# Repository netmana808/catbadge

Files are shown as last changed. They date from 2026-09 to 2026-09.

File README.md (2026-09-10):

# CatBadge case

A printable enclosure for the **large Retia CatBadge / ScriptKitty badge**, with screwless case catches, an independently removable battery cover, and six flanged buttons.

**Latest files: v8.7 case, v8.7a rear adhesion pads, and v8.7b taller buttons.** These are prototypes. Digital checks pass; printed fit, snap force, adhesion improvement and durability remain unverified.

**[Download the latest release](https://github.com/netmana808/catbadge/releases/tag/v8.7b)** · [Assembly guide](work/v8_7/README.md) · [Printing notes](PRINTING.md)

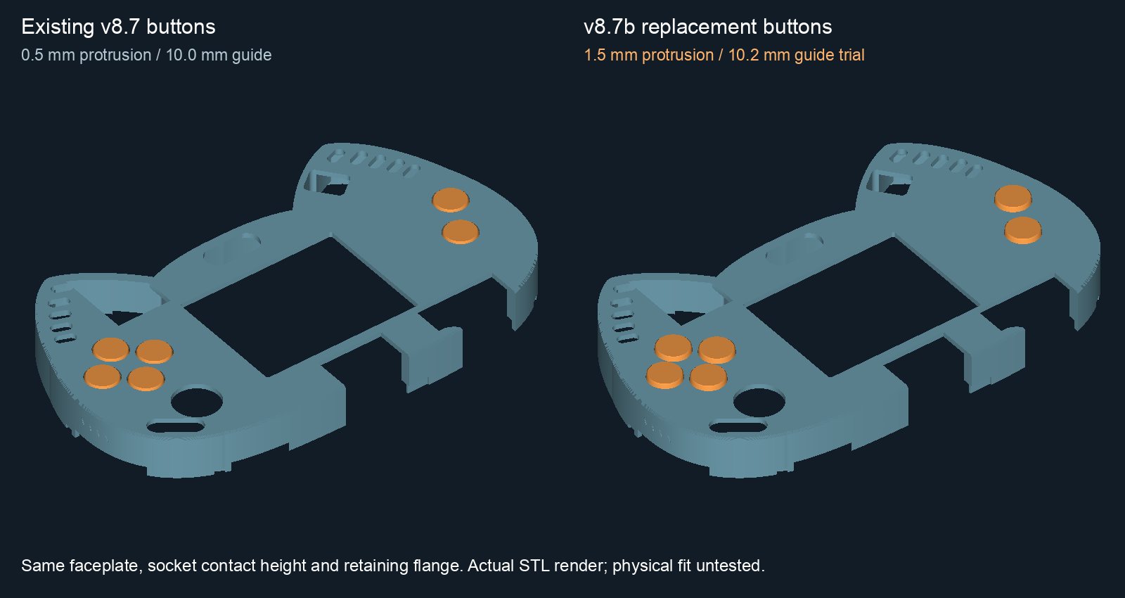
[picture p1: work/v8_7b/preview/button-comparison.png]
Original and taller buttons in the same faceplate, rendered from exported meshes


## Choose what to print

| What you need | Files | Notes |
| --- | --- | --- |
| Complete closed-back case | [v8.7 combined 3MF](work/v8_7/CatBadge-v8.7-COMBINED-CLOSED-BACK.3mf) | Front, rear, cover and original-height buttons; spring-antenna access retained. |
| Rear with extra bed attachment | [v8.7a rear-only 3MF](work/v8_7a/parts/CatBadge-v8.7a-Rear-Tray-Adhesion-Tabs.3mf) | Four removable pads; reuse the v8.7 front and cover. |
| Taller buttons for the same front | [v8.7b six-button set](work/v8_7b/CatBadge-v8.7b-SIX-cap_G10p2_S3p2_PLUS1mm.3mf) | Provisional 10.2 mm guide / 3.2 mm socket; test first. |
| Case snap test | [v8.7 snap coupons](work/v8_7/PRINT_FIRST_v8.7_Snap_Only.3mf) | Compare retention before printing a complete case. |
| Button fit comparison | [v8.7b six fit trials](work/v8_7b/PRINT_FIRST_v8.7b_Button_Fit_Trials.3mf) | Guide and socket sizes are separate choices. [Identification map](work/v8_7b/preview/fit-trial-layout.png). |
| Pad-removal test | [v8.7a ear-tip coupon](work/v8_7a/tests/PRINT_FIRST_v8.7a_Ear_Pad_Removal.3mf) | Tests contact and trimming, not full-case warping. |

**For the newest combination**, use a [v8.7 front](work/v8_7/parts/faceplate.3mf), [v8.7 battery cover](work/v8_7/parts/battery_cover.3mf), v8.7a rear and your selected v8.7b buttons. The v8.7 combined file retains its original rear and buttons; it does not automatically include the later replacements.

The [NO-SPRING-ONLY front](work/v8_7/parts/faceplate_NO_SPRING_ONLY.3mf) and [matching combined kit](work/v8_7/CatBadge-v8.7-COMBINED-CLOSED-BACK-NO-SPRING-ONLY.3mf) require the original spring antenna to be absent. Both front variants retain SAO access.

All STL/3MF dimensions are millimeters. The 3MFs contain geometry only, without a printer profile or G-code. Use release assets for direct downloads, or GitHub's raw/download button for individual files.

## What's new

### v8.7 — closed rear and reinforced joint

- Closes the rear vents and large rear-ear windows while retaining battery and service access.
- Increases the rear floor from 1.6 to 2.4 mm, outward from the board.
- Widens four catches to 8 mm and thickens the mating tongue to 1.4 mm.
- Uses 0.35 mm nominal engagement, with 0.25 / 0.35 / 0.45 mm coupons.
- Moves the battery-cover interface outward 0.8 mm to match the thicker rear.

The screen opening remains **52.5 × 40 mm**, with LED slots, open SAO access, and the antenna connector in the rear tray's outer ear slope. Main shell depth is approximately **23.2 mm**, or **31.5 mm over the battery cover**. Loaded-holder design envelope: **15.7 × 32.7 × 59.7 mm**. Actual adapter body, cable bends and complete electronics clearances need a fit check.

### v8.7a — removable rear adhesion pads

Two **24 mm diameter** ear-tip pads and two **20 mm** lower-corner pads increase first-layer contact. They are **0.4 mm thick** and should be trimmed flush after cooling. Print envelope: **154 × 112 mm** before a brim. The case interfaces match v8.7 within export precision.

This responds to a report of both rear ears lifting during a PETG print. The failed file and settings were not confirmed, so the pads are a trial rather than a proven cure. [Rear reprint guide](work/v8_7a/README.md).

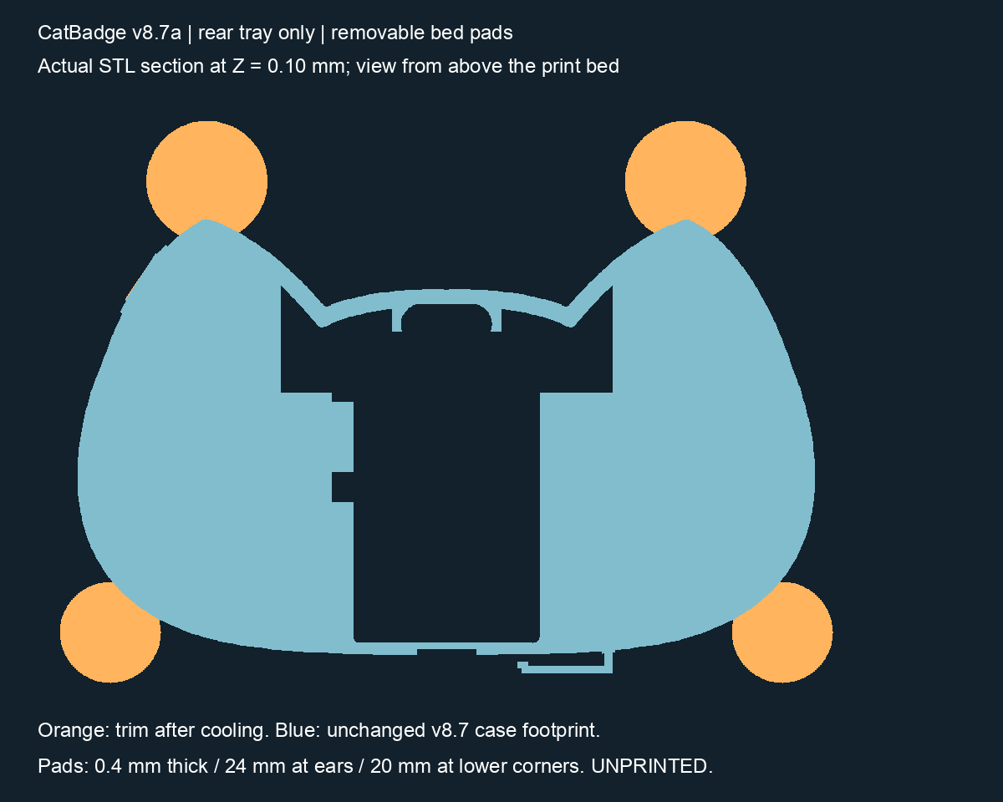
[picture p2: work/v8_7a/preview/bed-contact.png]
Actual rear STL bed-contact section; orange areas are removable pads


### v8.7b — taller button fit trials

- Adds **1 mm** to the exposed end: nominal protrusion increases from **0.5 to 1.5 mm**.
- Offers **10.0 / 10.2 / 10.3 mm** guides in the existing 10.6 mm opening.
- Retains socket contact height, 1.5 mm socket depth, 4.8 mm boss and 11.4 mm retaining flange.
- Includes **3.0 / 3.1 / 3.2 / 3.3 mm** socket trials and six-button sets for the provided combinations.

A closer guide is intended to reduce side play but must still move freely. Flanges stop outward escape; buttons can still fall out through the rear of a removed front. [Button selection guide](work/v8_7b/README.md).

## Printing and assembly

1. Start with the relevant fit coupons and inspect the sliced paths.
2. Keep the supplied orientations: **front and buttons face down; rear and cover exterior down**. Button sockets face up. The parts are designed for printing without supports at 0.20 mm layers; check your slicing result.
3. Print the padded rear separately, centered on the bed, with a connected brim. Let it cool before trimming while supporting the ears.
4. Check the empty case before installing electronics. With power removed, test free button sliding and gentle socket fit. Every button must release; no switch should be held down at rest.
5. Keep the matched v8.7 interfaces. V8.7a and v8.7b replace only their named parts; compatibility with older complete cases is not established.

See [PRINTING.md](PRINTING.md) for the proposed PETG starting trial. No script starts a printer job.

## Source and rebuild

Source is Python geometry code using NumPy, Shapely and Trimesh/Manifold. The full-case pipeline also uses OpenSCAD; VTK/Pillow render previews. This is not a native STEP model.

Use Python 3.12 and install OpenSCAD separately for full-case builds:

```sh
python3.12 -m venv .venv
.venv/bin/python -m pip install -r work/v8_7/requirements-resolved.txt
bash rebuild.sh v8.7b   # Buttons, checks and preview
bash rebuild.sh v8.7a   # Padded rear, coupon and checks
bash rebuild.sh v8.7    # Full case, coupons, checks and previews
```

`bash rebuild.sh all` runs all three. `v8.4` remains available for the original public release. The root script detects OpenSCAD on PATH or in `/Applications/OpenSCAD.app`; use `OPENSCAD_BIN=/path/to/OpenSCAD` for a custom executable and `CATBADGE_PYTHON` for an existing Python environment.

To check supplied case files without regenerating them:

```sh
.venv/bin/python work/v8_7/source/validate_v87.py --standalone
.venv/bin/python work/v8_7/source/check_overhangs.py
```

The root `rebuild.sh` is the public entry point. Historical local-workspace scripts are retained as provenance; some require unpublished baseline inputs. Standalone validation skips only unavailable historical-input checks and still checks supplied meshes and mechanical interfaces. The v8.7a/v8.7b builders include their reference meshes and validation.

## Validation and history

| Version | Digital checks | Physical status |
| --- | --- | --- |
| [v8.7](work/v8_7/validation.json) | 20 printable solids; formats, layout, snap/cover/button clearances; [layer support checks](work/v8_7/overhangs.json) | Complete fit, strength and snap feel unverified |
| [v8.7a](work/v8_7a/validation.json) | Single-solid rear/coupon; preserved case interfaces; additions confined to bed pads within export tolerance | Adhesion improvement and removal untested |
| [v8.7b](work/v8_7b/validation.json) | Six variants; 648 free-motion and 72 flange-stop checks; retained socket interfaces | Sliding fit, socket grip and switch return untested |

These checks do not establish manufacturing tolerances or allowable switch stroke. Only the original v0.1 tray/open frame has explicit user-confirmed fit. Release assets include source, validation, previews and SHA-256 checksums. The [v8.4 release](https://github.com/netmana808/catbadge/releases/tag/v8.4) remains available.

## Attribution

Independent enclosure for [RetiaLLC/DefconBadge2026](https://github.com/RetiaLLC/DefconBadge2026), not an official Retia product. PCB geometry and component-source credit belong to the badge designers. See [ATTRIBUTION.md](ATTRIBUTION.md).

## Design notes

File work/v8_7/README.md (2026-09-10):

# CatBadge v8.7 — closed back and reinforced snap rim

V8.7 responds to a physical print reported as flimsy and difficult to snap together satisfactorily. The printed version and slicer settings have not been confirmed, so this is a geometry revision with fit trials, not a diagnosis of the printer.

## Changes

- Close the six rear vent slots and the large rear ear windows. Battery access, UART, QWIIC, lanyard and the existing side service openings remain available. A continuous rear border ties the center section to the ears beneath the side-access header cutouts.
- Increase the main rear panel from **1.6 to 2.4 mm**, outward from the board. Its inner face remains at Z=-8 mm, preserving the existing rear component clearance.
- Increase the overlapping faceplate tongue from **1.15 to 1.4 mm nominal thickness** and widen all four catches from **5 to 8 mm**.
- Select **0.35 mm engagement**, with 0.25, 0.35 and 0.45 mm print-first trials. Preserve the 0.30 mm nominal mating gap. Widen the matching tray pockets and move the release notches clear of the wider catches.
- Move the battery cover and its mating tabs/slots/latch interface outward **0.8 mm** for the thicker rear panel. Cover shape, independent sliding access and the loaded-holder envelope are retained.
- Retain the v8.4 exterior finishing, beveled caps, 52.5 x 40 mm screen opening, LED slots, open SAO and rear outer-ear antenna port.

The catches remain opposed ramped detents, designed to release through outward rim flex. A more substantial rim, wider engagement and a closed rear panel are intended to improve feel; no physical retention force, stiffness or cycle-life claim follows from the CAD checks. These are not square permanent locking hooks.

**Print the v8.7 faceplate, rear tray and battery cover as a matched set.** Earlier shells are not the fit target. V8.4 button caps retain their geometry and may be reused if their sockets already fit gently.

## Downloads and orientation

- `CatBadge-v8.7-COMBINED-CLOSED-BACK.3mf`: default faceplate with original spring-antenna access, rear tray, battery cover and six 3.2 mm TRIAL socket caps.
- `CatBadge-v8.7-COMBINED-CLOSED-BACK-NO-SPRING-ONLY.3mf`: alternative faceplate; use only if the original spring antenna is absent. SAO remains open.
- **`PRINT_FIRST_v8.7_Snap_Only.3mf`**: three engagement trial lids and their shared tray coupon; start here.
- `PRINT_FIRST_v8.7_Fit_and_Comfort.3mf`: 16 objects, including three rim-fit trials, shared tray coupon, battery latch pair, four socket trials, front-button coupon, LED/SAO and screen checks, finishing samples and a closed rear-ear sample.
- `PRINT_FIRST_v8.7_Comfort_Only.3mf`: the three finishing samples.

Individual STL and 3MF files are in `parts/` and `tests/`. Each complete kit has nine named objects in a nominal 220 x 220 mm layout before brims. All units are millimeters. These are geometry-only 3MFs, without a printer profile or G-code.

Keep the exported orientations: faceplate and caps face down; rear tray and cover exterior down. The exported geometry is checked with a 0.2 mm layer / 45-degree support envelope. Inspect the actual sliced paths and any local bridges before printing.

## PLA+ print and fit trial

With a **0.4 mm nozzle**, a starting trial is **0.20 mm layers, four walls/perimeters, and six top/bottom layers**, using the filament maker's temperature range. This is a suggested trial, not a verified Anker/eufy profile. The 1.4 mm tongue may resolve into fewer than four extrusion lines; inspect the preview for filled, continuous material rather than relying on the wall-count setting alone. Shell walls matter more than simply increasing infill.

1. Print the shared rim tray and 0.25 mm engagement lid first. Compare the 0.35 mm trial if the first is loose. Use 0.45 mm only as a comparison after the gentler trials; do not force a tight joint.
2. Confirm that the coupon seats fully, has useful retention and releases through the notch. Gaps between extrusion lines, split layers, whitening or cracks are failed results.
3. Check repeated gentle opening/closing; twenty cycles can be an initial screening test, not lifetime qualification. The cropped coupon has different stiffness from the complete perimeter.
4. Check both empty v8.7 shell halves before fitting electronics. The combined file uses the middle 0.35 mm trial. Test the shifted battery cover and latch separately.
5. For untested cap sockets, start at 3.3 mm and work downward to a gentle fit. The combined kit's 3.2 mm socket remains provisional.

If the halves cannot seat, check for first-layer spread, an unseated PCB/cap, misplaced antenna cable or tight engagement. If a fully seated seam barely retains, compare the next engagement coupon. If the printed rim itself separates along layers or shows gaps, check extrusion and layer bonding before increasing engagement. Do not use screws, glue or force to overcome a mismatch.

## Assembly and reopening

Remove power. Fit the antenna adapter with its real metal nut and route its cable clear of the board seat, rim and battery-cover path. Check the newly enclosed rear-ear area: it retains 8 mm nominal rear clearance, but the actual adapter body, U.FL lead bend and other components are not fully modeled. Keep the existing side connector and top UART/QWIIC paths clear.

Seat the PCB and gently fitted caps, align the faceplate, then seat the perimeter next to the catches. Do not press on the screen or switches. Use a thin plastic pick in the exterior notches to ease the outer faceplate rim outward and lift it away, releasing catches progressively. Stop if the rim needs force or shows stress damage.

The digital release path prescribes up to 0.55 mm local outward displacement for the selected 0.35 mm engagement, then checks separation. This is a collision model, not a measured deflection limit or force recommendation.

To open the battery cover, press its bottom-edge latch toward the badge center, slide 3.2 mm toward assembly +X (right viewed from the front), and lift away from the rear. Install in reverse. The main case can stay closed.

Button flanges prevent outward escape while assembled; caps can still exit the rear of a removed faceplate. No extra keeper plate or case screws are required.

## Dimensions and validation limits

- Width: approximately **147.96 mm**, unchanged.
- Main shell depth: **23.2 mm**; over the battery cover: **31.5 mm**; including button faces: **32.0 mm**. The 0.8 mm increase buys rear-panel thickness while preserving electronics clearance.
- Faceplate skin remains 1.6 mm. Screen opening remains **52.5 x 40 mm**, with right edge X=26.46 and left edge X=-26.04.
- Measured loaded holder: **15.7 high x 32.7 wide x 59.7 long mm**. Its assumed top remains at the PCB underside; leads and mounting offsets require a real fit check.
- The antenna bore remains a **6.5 mm trial** with a 2.4 mm clamping land; exact adapter fit is unverified.

`validation.json` reloads 20 unique printable solids, verifies STL/3MF surfaces and kits, and checks assembly, PCB seat, service access, button motion, rim engagement/release and battery-cover travel. Revision checks prove former vent/ear closure, increased engagement geometry, the cover translation and retained button geometry. They do not measure snap force or structural stiffness. `overhangs.json` checks 0.2 mm layers with 0.205 mm lateral growth and at most 0.025 mm² residual per layer.

The user has reported poor fit/feel on an earlier print; its exact version and settings are not yet confirmed. **V8.7 is unprinted and physically unverified.** Mesh/render checks do not establish thermal, drop, fatigue, connector or full electronic-assembly performance.

## Rebuild

From the local design repository, with its Python environment and OpenSCAD installed:

```sh
bash rebuild.sh v8.7
```

From the extracted ZIP, use Python 3.12, the dependencies in `requirements-resolved.txt`, and OpenSCAD on PATH:

```sh
python source/generate_v87.py --coupons
python source/validate_snaps.py
python source/check_overhangs.py --coupons
python source/generate_v87.py
python source/validate_v87.py --standalone
python source/check_overhangs.py
python source/render_v87.py
```

`generate_v87.py` is the entry point; earlier generators are geometry helpers. All previews are generated from exported meshes; PCB display geometry is only a simplified reference. The package contains source, parameters, parts, coupons, previews and reports. CRC and per-file SHA-256 checks verify the ZIP; download checksums are in `SHA256SUMS`.

## References and credit

- [RetiaLLC/DefconBadge2026](https://github.com/RetiaLLC/DefconBadge2026): original hardware and PCB outline. Independent enclosure; upstream design credit remains with its designers.
- [Protolabs snap-fit guidance](https://www.hubs.com/knowledge-base/how-design-snap-fit-joints-3d-printing/): local flexibility, width, strain, build orientation and fit iteration; printed tolerances are not universal.
- [Prusa layers and perimeters](https://help.prusa3d.com/article/layers-and-perimeters_1748): shell thickness and perimeter settings affect strength. The suggested PLA+ profile above still needs a coupon test.
- [Prusa modeling guidance](https://help.prusa3d.com/article/modeling-with-3d-printing-in-mind_164135): orientation, chamfers and tolerances.
- Supplied Cynthion case: earlier rim/catch reference only; original meshes are not redistributed.

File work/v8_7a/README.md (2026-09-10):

# CatBadge v8.7a — rear tray with removable adhesion pads

Back-only reprint trial for the report that both rear ears lifted off the bed. This is the v8.7 rear tray with four sacrificial bed pads; the original case geometry is preserved within export precision. Use with the existing **v8.7** front and battery cover. Compatibility with other versions is not established, and the reported failed print file is not confirmed.

- [Rear tray 3MF](parts/CatBadge-v8.7a-Rear-Tray-Adhesion-Tabs.3mf)
- [Rear tray STL](parts/CatBadge-v8.7a-Rear-Tray-Adhesion-Tabs.stl)
- [Print-first ear/pad removal coupon](tests/PRINT_FIRST_v8.7a_Ear_Pad_Removal.3mf)
- [Bed-contact preview](preview/bed-contact.png)
- [Digital validation](validation.json)

## What changed

Two 24 mm diameter pads overlap the ear tips; two 20 mm pads overlap the lower outside corners. All are 0.40 mm tall and join the case directly at bed level. They add approximately 1,434 mm² of first-layer contact and 572 mm³ of material. The complete print envelope is 154 × 112 × 12.2 mm, or at most 170 × 128 mm including an 8 mm brim.

These are removable adhesion aids, not permanent case extensions or overhang supports. The 2.4 mm rear floor, snap rim, PCB seat, antenna port, battery opening and cover interfaces retain the v8.7 geometry. Do not thicken the floor or add internal ribs for this trial: those require electronics-clearance review and would not directly anchor the ear tips.

The pads target corner lifting but do not guarantee a warp-free print. The cause of this print's lifting remains unconfirmed. [Prusa's warping guidance](https://help.prusa3d.com/article/warping_2011) recommends a brim and, for persistent local lifting, small removable cylinders a few layers tall. The particular dimensions here are a design trial, not a manufacturer-validated M5C recipe.

## Reprint

1. Print the small coupon first to check first-layer contact and pad trimming. It is a cropped real ear tip with its pad and 2.4 mm floor. It does not predict full-case thermal warping or test the snaps.
2. Import the rear **by itself**, at 100% scale. Keep its exterior flat face and all four pads on the bed, open interior facing up. Center it on the plate.
3. For an M5C with compatible PETG, the proposed adhesion trial is 0.20 mm first/subsequent layers, four walls, 20 mm/s first layer, 240°C nozzle / 80°C bed, 8 mm outer brim with zero gap. Supports stay off. The 3MF contains geometry only; enter settings in your slicer. See the public repository PRINTING.md for context.
4. In the sliced preview, check that each pad touches the case and prints for two layers, and that the brim joins the exterior/pads. No slicing or printer job was performed during this CAD change. Keep direct AC/fan drafts away and prepare the actual plate surface appropriately; its coating remains unconfirmed.
5. Let the print and plate cool. Support each ear while carefully trimming the thin pads flush to the original case outline. Avoid twisting an ear to snap off a pad. Clear brim/pad remnants before trying the front and battery cover.

Reuse your front and cover if they are v8.7 and usable. No new screws or permanent support plate are required. Record the exact source file, selected profiles, whether corners stay down, pad-removal behavior and fit. Physical print results are pending.

## Source and verification

From the public checkout run `bash rebuild.sh v8.7a`. This rebuilds only v8.7a. The included `reference/rear_tray_v87.stl` is the untouched v8.7 geometry input; the original version's parametric sources remain in `work/v8_7/source/`. The input hash is recorded in `validation.json`.

The standalone `source/build.py` also runs from an extracted package using a Python environment with `source/requirements.txt`. It creates the coupon first, exports and reloads both STL/3MF pairs, verifies millimeter units and named single-solid objects, compares the rear against the reference, checks holes remain open, and checks the 0.20 mm layer support envelope. Numerical acceptance is 0.003 mm³ for export residual volumes and 0.025 mm² for section differences, not a physical fit allowance. The actual maximum section difference above the pads is approximately 0.00023 mm².

The PCB source is RetiaLLC/DefconBadge2026; this is an independent enclosure prototype. Existing v8.7 physical fit uncertainties remain. Physical validation is pending.

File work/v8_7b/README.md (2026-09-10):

# CatBadge v8.7b — taller replacement buttons

Replacement buttons for the **existing v8.7 faceplate**, including its NO-SPRING-ONLY variant. No front, back, cover or keeper plate needs to be printed. Compatible by geometry with the v8.7a rear derivative. The printed front's exact version and button fit symptoms remain unconfirmed; these are physical fit trials.

- **[Print-first six-button fit comparison](PRINT_FIRST_v8.7b_Button_Fit_Trials.3mf)**
- **[Six matching buttons: 10.2 mm guide / 3.2 mm socket](CatBadge-v8.7b-SIX-cap_G10p2_S3p2_PLUS1mm.3mf)** — provisional default; choose after testing
- [Actual mesh comparison](preview/button-comparison.png)
- [Trial-plate identification map](preview/fit-trial-layout.png)
- [Validation report](validation.json)

## Changes and retained interfaces

The face extends **1.0 mm farther outward**, increasing nominal protrusion from **0.5 to 1.5 mm** above the local faceplate. The old cap's actual assembly top is Z=13.3 mm and the new one is Z=14.3 mm; the faceplate is Z=12.8 mm. An earlier generator default of Z=13.7 was superseded by v8.1 and is not the v8.7 export height.

The main trial increases guide diameter from **10.0 to 10.2 mm** inside the unchanged 10.6 mm guide bore. Nominal radial clearance reduces from 0.30 to 0.20 mm, intended to reduce side play. A 10.3 mm comparison offers 0.15 mm radial clearance. Smaller clearance can bind on an imperfect print; use the trial that moves freely rather than selecting the largest by default.

The 0.3 mm top bevel is retained. The flange transition remains 45 degrees for face-down printing. Socket roof/contact height stays at Z=6.8 mm; socket depth remains 1.5 mm, boss diameter 4.8 mm, entry chamfer unchanged. The retaining flange remains 11.4 mm diameter at Z=9.8–10.8 mm. The taller exposed end does not extend the socket toward the board. Actual switch preload, permissible stroke, return and socket grip still require checking on the real badge.

The existing flange prevents outward escape; these buttons can still fall out through the rear of a removed faceplate. No new latch or interference-fit retention is claimed.

## Fit trial

The comparison plate contains six separate caps. G identifies the faceplate guide diameter; S identifies the socket bore diameter. Both are CAD dimensions in millimeters.

| Position in supplied plate, viewed from above | Guide | Socket | Purpose |
| --- | ---: | ---: | --- |
| Front/lower row, left | 10.0 | 3.2 | Original guide diameter with new height |
| Front/lower row, middle | 10.2 | 3.2 | Main reduced-play trial |
| Front/lower row, right | 10.3 | 3.2 | Closer guide trial |
| Back/upper row, left | 10.2 | 3.3 | Looser socket trial |
| Back/upper row, middle | 10.2 | 3.1 | Smaller socket trial |
| Back/upper row, right | 10.2 | 3.0 | Smallest socket trial |

The slicer object names retain these dimensions. Keep them in order after removal; no tiny embossed identifiers were added to the sliding or contact surfaces. Auto-arranging changes the map, so use object names if rearranged.

1. Print at 100% scale with the exported **button faces down / sockets up** orientation. Use 0.20 mm layers and a 0.4 mm nozzle, with supports off. Use settings suitable for your material; there is no material profile or G-code embedded in these geometry-only 3MFs. Inspect first-layer spread and socket paths in the slicer.
2. Allow cooling and remove brim remnants without rounding the guide or filling the socket. Test each guide in the removed faceplate before installing it on a board. It must move freely without scraping or sticking. Compare all six locations in the actual front.
3. With power removed, start socket testing at 3.3 mm if the existing size is unknown, then work downward only to a gentle fit. Do not force the cap onto a switch. These separate trials distinguish faceplate clearance from socket grip.
4. Once assembled, verify every button releases and the switches are not held down at rest. The numerical collision offsets in the report are not permission to depress the real switch by that amount. A cap that only works when forced, sanded heavily or pressed against a stressed switch is a failed fit.
5. Use the matching `CatBadge-v8.7b-SIX-...` file for the selected combination. Six-piece files exist for each of the six tested combinations. Individual STL/3MF pairs are in `parts/`. If the best guide and socket require an unprovided combination, generate that combination and rerun the checks before printing a set.

The existing v8.7 combined case kit still contains its original caps. These button-only files are a separate replacement, not an updated full-case kit. If the original guide already sticks, neither the 10.2 nor 10.3 trial is a corrective recommendation; provide that result before shrinking a new guide variant.

## Verification and rebuilding

The standalone source uses the existing NumPy/Trimesh/Shapely/Manifold pipeline. Included reference meshes are untouched v8.7 faceplate variants and socket-cap exports, with hashes recorded in `validation.json`. Their upstream case/PCB attribution remains RetiaLLC/DefconBadge2026; this is an independent enclosure prototype.

From the public checkout: `bash rebuild.sh v8.7b`. From an extracted package, install `source/requirements.txt` in a local virtual environment, then run `python source/build.py` and `python source/render.py`. These produce geometry and reports only.

Validation reloads six printable STL/3MF pairs, checks single watertight solids, positive volume, names, millimeter units and matching bounds/volume. It checks retained socket/flange sections against each original socket size, the 1 mm height change, support envelopes at 0.2 mm layers, adjacent-button clearance, **648 cap/faceplate motion cases** and **72 flange-stop cases**. The collision tests include both faceplate variants, all six positions and ±0.1 mm lateral offsets at rest. A nonintersecting CAD assembly does not establish low friction, low wobble, switch return or manufactured fit. No print or actual slicer toolpath validation has occurred.

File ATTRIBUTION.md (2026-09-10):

# Attribution and licensing notes

- **Badge hardware:** [RetiaLLC/DefconBadge2026](https://github.com/RetiaLLC/DefconBadge2026), specifically `hardware/kicad/2024_def_con_badge_v1.kicad_pcb`. The enclosure helpers transcribe the board outline and selected footprint locations; they do not contain a complete electronics assembly. Credit and ownership of the upstream hardware remain with its designers.
- **Enclosure:** independent CatBadge case development, published by `netmana808`. The versioned releases retain the local project's source, geometry, measured constraints and validation artifacts.
- **Snap-fit reference:** locally supplied Cynthion case meshes informed the overlapping rim and catch concept. Those Cynthion meshes are not redistributed. Inspection measurements and file hashes are recorded in `work/v8_4/reference/cynthion_joint_measurements.json`; their dimensions are not validated CatBadge tolerances.
- **Tools:** NumPy, Shapely, Trimesh, Manifold, OpenSCAD, VTK and Pillow retain their respective licenses. Their applications, source distributions and fonts are not bundled.

The upstream repository did not expose a top-level license file or a detected license through GitHub when checked for this publication on 2026-09-09. No blanket license is assigned here to upstream or third-party material. Public availability alone should not be treated as a separate license grant. This publication does not relicense the badge hardware.

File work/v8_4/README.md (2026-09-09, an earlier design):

# CatBadge v8.4 — compact handheld polish

V8.4 softens exposed edges and adds subtle cheek grips while retaining the v8.3 size, four integral rim catches and independent sliding battery cover. It uses the existing PLA+ workflow and requires no case screws or separate keeper plate.

The front and rear exterior perimeter edges and battery-cover exterior edge have nominal **0.6 mm, 45-degree bevels**. The antenna mounting land, battery latch beam/root/tooth, sliding tabs and mating surfaces are protected from these cuts. The latch guards receive smaller 0.25 mm edge bevels and 0.30 mm rounded vertical corners to keep their corners within the print envelope. Layered perimeter bevels use 0.05 mm CAD increments; the button bevel is a continuous revolved surface.

All six button faces retain their flat round tops and gain **0.3 mm edge bevels** (9.4 mm flat top, original 10 mm guide diameter below the bevel). Stems, sockets, captive flanges and projection are preserved. Each cheek has **four shallow, rounded grip lines**, nominally 2.4 mm long, 0.8 mm wide and 0.25 mm deep, angled 20 degrees in mirrored directions. They are recessed into the outer wall, clear of catches and ports. The exterior entrances to the four release notches gain a 0.25 mm bevel; their internal access and catches remain unchanged.

This is an **unprinted PLA+ prototype**. The supplied Cynthion case informed the overlapping rim and local catches; its dimensions were not copied as validated CatBadge tolerances. Digital clearance and mesh checks do not establish physical snap force or fatigue life. Only the original v0.1 case has user-confirmed physical fit.

## Print files

- **`CatBadge-v8.4-COMBINED-HANDHELD.3mf`** — default, with original spring-antenna access retained in the left ear.
- `CatBadge-v8.4-COMBINED-HANDHELD-NO-SPRING-ONLY.3mf` — alternate with both ear faces closed around the LED stripes; use only if the original spring antenna is absent. SAO stays open.
- **`PRINT_FIRST_v8.4_Comfort_Only.3mf`** — cheek-grip coupon, battery-cover edge coupon and one 3.2 mm socket button cap: a quick three-piece feel check.
- **`PRINT_FIRST_v8.4_Fit_and_Comfort.3mf`** — all 15 coupons/trials: the comfort samples, three rim-fit trials, shared tray, battery latch pair, front-button section, four cap socket sizes, LED/SAO section and screen ring.

Each combined file contains **9 named objects**: one faceplate, one rear tray, one battery cover and six button caps. Select one combined file; the two faceplates are alternatives. There are no separate case pins, screws or nuts. The antenna adapter still uses its own real metal retaining nut.

Individual STL and 3MF files are under `parts/` and `tests/`. All geometry uses millimeters. The combined layout fits within a nominal 220 x 220 mm area before brims; it contains no printer profile or G-code. Keep the supplied orientations: faceplate and caps face down, tray and battery cover exterior down. The exported ramps pass the project's 0.2 mm layer / 45-degree support-envelope check. Inspect the slicer's actual thin-wall and first-layer paths before printing.

**V8.4 retains the v8.3 mechanical interfaces.** Exported-mesh checks cover both directions of mixed v8.3/v8.4 faceplate/tray, battery-cover/tray and button/faceplate combinations. Physical interchangeability still needs a fit check. These case halves do not mate with the earlier v8/v8.1 pin-mounted halves.

## Rim and catches

The outer faceplate tongue overlaps the rear tray at the seam. The nominal side gap is 0.30 mm; the faceplate tongue is approximately 1.15 mm thick and extends 3.0 mm below the original internal mating plane. The PCB seat and upper restraint retain the original 0.2 mm nominal board float. The tongue stays outside the board-clearance envelope.

Four 5 mm wide catches sit on the two upper cheek walls and two lower cheek curves. The catches point inward into matching tray recesses; the faceplate rim flexes outward during engagement/release. Both catch flanks are shallow ramps. These are releasable detents, not square locking hooks. Small exterior notches beside the catches allow a thin plastic pick to reach the seam without entering the PCB space.

The full case selects **0.25 mm nominal engagement**. The three coupon faceplates use 0.15, 0.25 and 0.35 mm engagement and share the same mating tray. These numbers describe engagement, not tongue thickness or clearance. Their files are named `PRINT_FIRST_rim_lid_0p15`, `0p25`, `0p35`, and `PRINT_FIRST_rim_tray`.

The catch roots use the continuous curved rim rather than narrow upright hooks. Local fit still depends on the filament, layer adhesion and slicer paths. The cropped coupon has different overall stiffness from the full case, so passing it is followed by an empty-case fit check. The inherited source parameter `P['catch_overlap']` in `source/generate_v83.py` controls full-case engagement; changing it requires regeneration and validation of both kits and parts.

## Fit sequence

1. Print the three-piece comfort set to assess the bevels, grip texture and button feel. Then print the shared rim tray and the 0.15 mm coupon lid first. Progress to the 0.25 mm and 0.35 mm trials only to compare retention. Select a fit that seats and releases gently. Whitening, cracking or a seam requiring force is a failed fit.
2. Check repeated opening and closing on the coupon. Twenty cycles is a useful initial screening exercise, not a lifetime qualification.
3. Check the two empty v8.4 case halves together before installing electronics. Confirm that the four catches retain the seam and release through their notches. The default full case corresponds to the 0.25 mm coupon.
4. Test button sockets from the largest 3.3 mm trial downward to a gentle fit. The combined case uses 3.2 mm provisionally. Verify the screen fit ring, retained button motion and any untested port/ear clearances.

## Assembly and reopening

Remove power. Fit the antenna adapter with its actual retaining nut, and route its cable clear of the rim, PCB seat and cover. Seat the board, then fit the six caps gently. Lower the faceplate squarely while aligning the cap faces with their guide holes. Apply light pressure at the perimeter adjacent to the catches until the rim seats. Do not use the screen, buttons or connector as pressing points. A misaligned case must not be forced together.

To reopen, use the small notches beside the four catches to ease the **outer faceplate rim outward**, then lift it away from the tray. A thin plastic pick can hold an already released section clear while working around the seam. Keep the pick in the external notch. Do not insert it over the PCB or lever against the board. Stop if the rim needs force or shows stress damage.

The release calculation prescribes up to 0.45 mm outward rim movement for the selected 0.25 mm trial, then checks axial separation. It is a geometric model, not an instruction to measure or force that displacement, and not a prediction of hand force or sequential release behavior. Verify the actual opening procedure on the empty case.

Button flanges prevent outward escape while assembled. The caps can still leave through the rear of a removed faceplate. There are no keeper plates or extra screws.

## Battery access

The existing cover remains independent of the main-case catches. To remove it, press its bottom-edge thumb latch toward the badge center (assembly +Y), slide the cover 3.2 mm toward assembly +X (right when viewed from the front), then lift it away from the rear. Install in reverse, sliding toward -X until it clicks. The main case stays closed during this operation.

The loaded holder envelope remains **15.7 mm high x 32.7 mm wide x 59.7 mm long**, with 1 mm modeled height allowance. Its modeled top is at the PCB underside; actual mounting offsets, leads and connector clearance still need physical verification.

## Preserved dimensions and access

- Main shell depth: **22.4 mm**; over the battery cover: **30.7 mm**; including button faces: **31.2 mm**. The new joint fits within this existing depth.
- Faceplate skin: **1.6 mm**; inner surface stays at Z=11.2 mm above the PCB underside, retaining 0.7 mm nominal clearance above the measured 10.5 mm screen before board float and print tolerances.
- Screen aperture: **52.5 x 40 mm**. Left edge X=-26.04, right X=26.46; Y=-27.99 to 12.01. The v8.1 right-side correction remains.
- Rear electronics clearance stays 8 mm and the floor stays 1.6 mm. No component heights or cable envelopes were guessed to reduce them.
- Six captive button flanges, all ten LED slots, open rotated SAO connector access, speaker, lanyard and existing service access remain.
- The 6.5 mm trial antenna port stays in the rear tray's outer left-ear slope with a 2.4 mm clamping land. Exact adapter shank, nut/washer, usable thread and cable-bend fit remain unverified.
- The default retains the left-ear spring access because removal of the original spring is unconfirmed. This revision makes no electrical, RF or firmware change.

## Validation and rebuild

`validation.json` records 19 unique printable solids; STL/3MF surface equivalence; 9 objects per full kit, 15 per full coupon kit and 3 per comfort kit; no overlap in the print layout; assembled clearances; retention at all four catches; outward-flex/separation checks for both faceplates; four external release-notch probes; battery-cover motion; 120 button offsets checked against both lids; PCB seat, screen, LED, SAO and antenna checks; exterior material removal without added bulk; all eight grip recesses; button and case bevels; protected mechanical sections; mixed v8.3/v8.4 assembly and motion checks; and protected baseline hashes.

`overhangs.json` checks exported print orientations one layer at a time at 0.2 mm, allowing 0.205 mm lateral expansion and at most 0.025 mm² numerical residual per layer. All parts pass this geometric envelope. It is not a printer-specific slicing or physical print result.

Previews are generated from the exported meshes. The front and rear assembly views include only a simplified PCB reference; electronics and cables are not modeled. `preview/snap_detail.png` is an actual cross-section of the mating meshes.

From the original repository root:

```sh
bash work/v8_4/run.sh
```

From an extracted package, with Python 3.12, the listed dependencies and OpenSCAD on PATH:

```sh
python source/generate_v84.py --coupons
python source/validate_snaps.py
python source/generate_v84.py
python source/validate_v84.py --standalone
python source/check_overhangs.py
python source/render_v84.py
```

`generate_v83.py`, `generate_v81.py`, `generate_v75.py` and earlier source modules are internal geometry helpers; use `generate_v84.py` as the build entry point. Finishing parameters live in `source/finish_v84.py`. Existing local tools were sufficient; no new system tooling was installed. The package includes source, parameters, individual meshes, test coupons, previews and reports. Archive CRC and each packaged file's SHA-256 are checked; distribution checksums are in `SHA256SUMS`.

## References

- [Prusa modeling guidance](https://help.prusa3d.com/article/modeling-with-3d-printing-in-mind_164135): bed-facing chamfers, print orientation and tolerance iteration.

- Local `cynthion_box.stl` and `cynthion_lid.stl`: measured overlapping rim and four local ramped catches; inspection measurements/hashes are recorded in `reference/cynthion_joint_measurements.json`. Supplied Cynthion mesh files are not redistributed in this package.
- [Formlabs snap-fit guide](https://formlabs.com/global/blog/designing-3d-printed-snap-fit-enclosures/): fit, print orientation, joint types and iterative physical testing.
- [Protolabs snap-fit guidance](https://www.hubs.com/knowledge-base/how-design-snap-fit-joints-3d-printing/): root geometry, deflection and clearance considerations. General process advice is not a PLA+ material qualification.
- [RetiaLLC/DefconBadge2026](https://github.com/RetiaLLC/DefconBadge2026): original PCB/outline source. Independent enclosure prototype; upstream design credit remains with its designers.

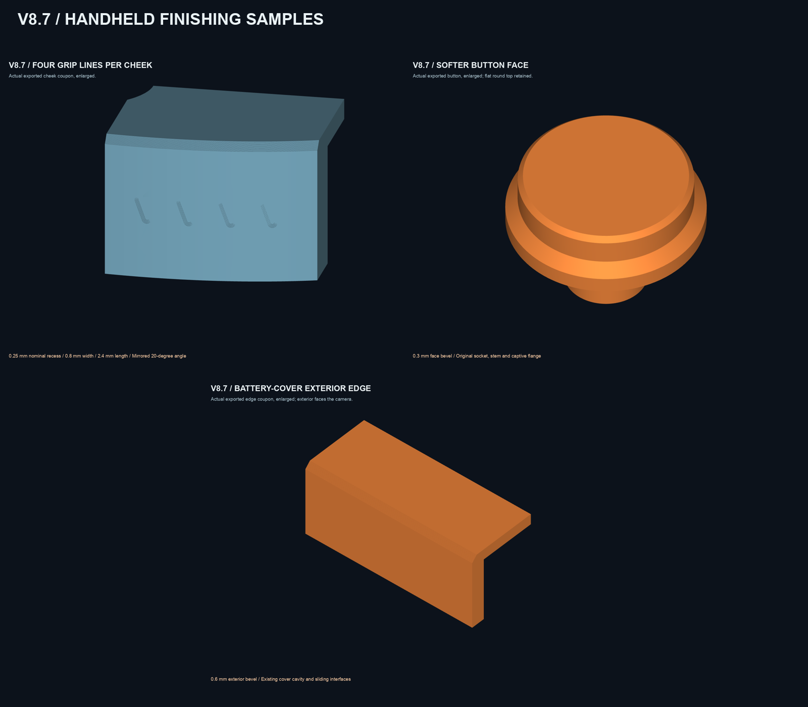
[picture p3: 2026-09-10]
work/v8_7/preview/comfort.png

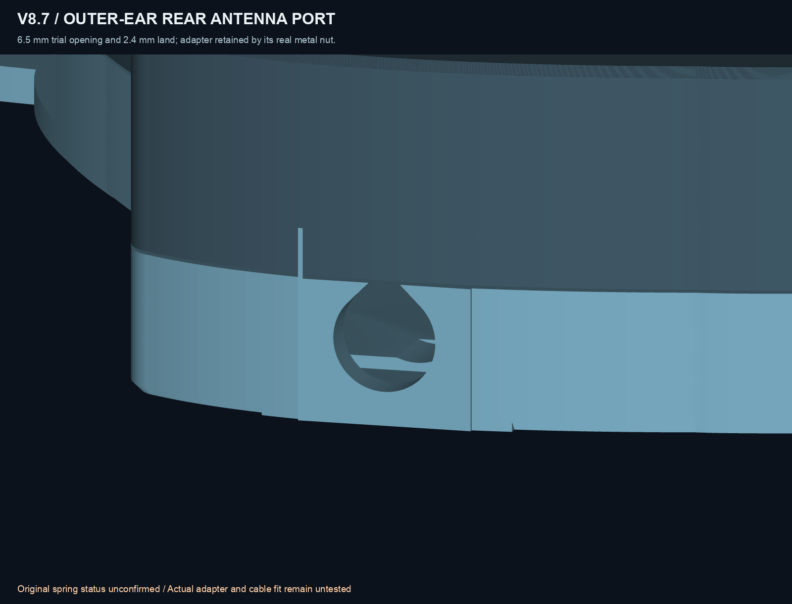
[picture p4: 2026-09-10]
work/v8_7/preview/antenna.png

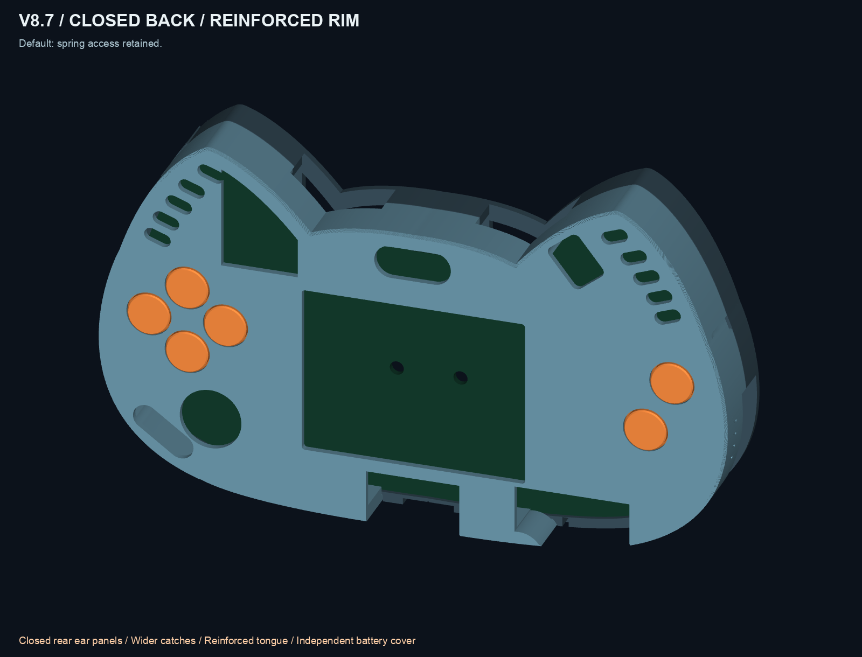
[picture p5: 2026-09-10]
work/v8_7/preview/front.png

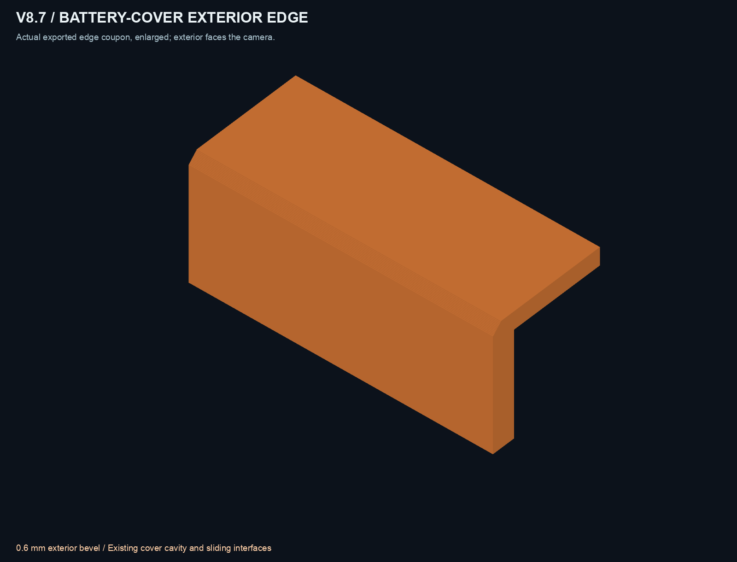
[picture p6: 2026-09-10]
work/v8_7/preview/cover_detail.png

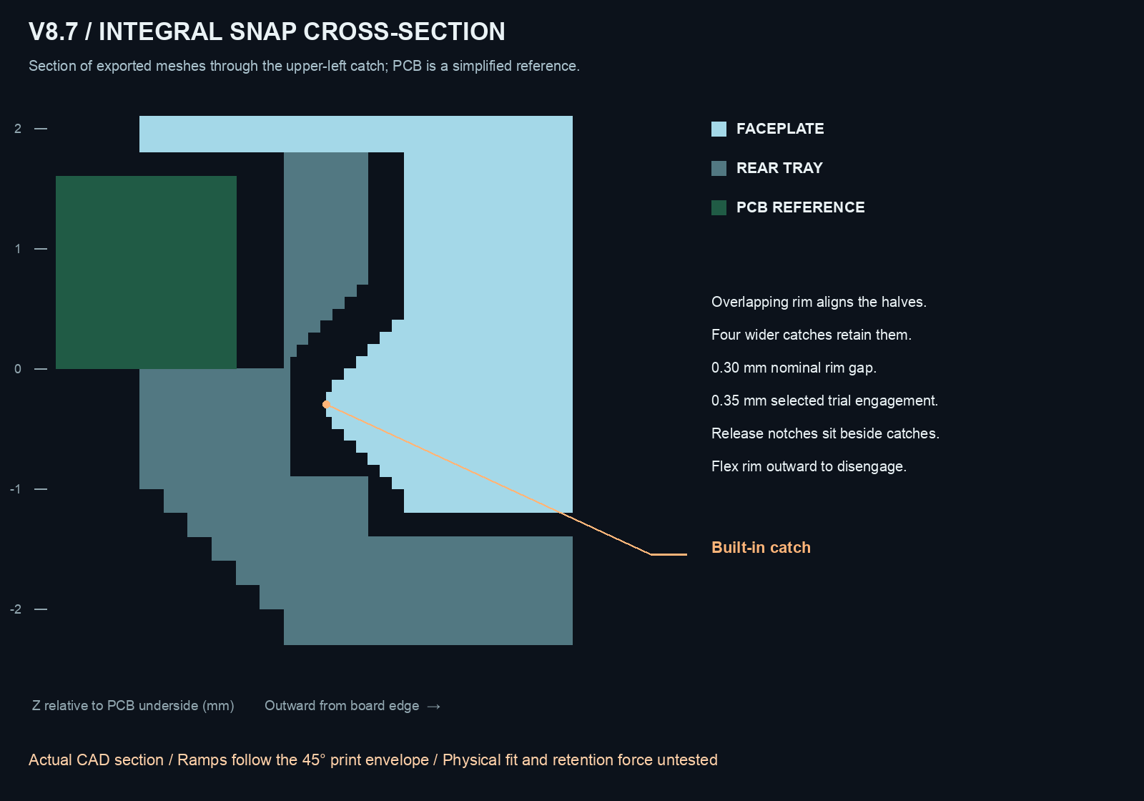
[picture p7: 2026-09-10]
work/v8_7/preview/snap_detail.png

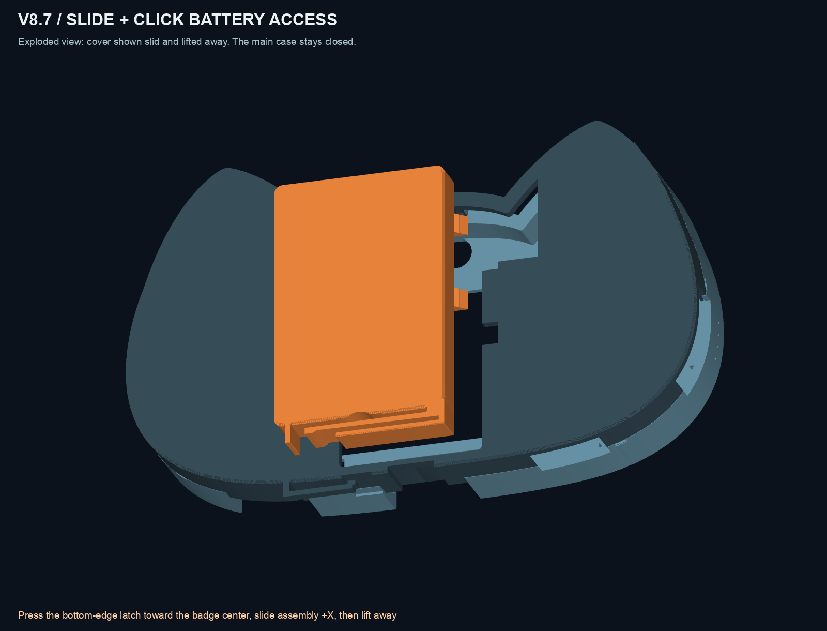
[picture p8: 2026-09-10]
work/v8_7/preview/rear.png

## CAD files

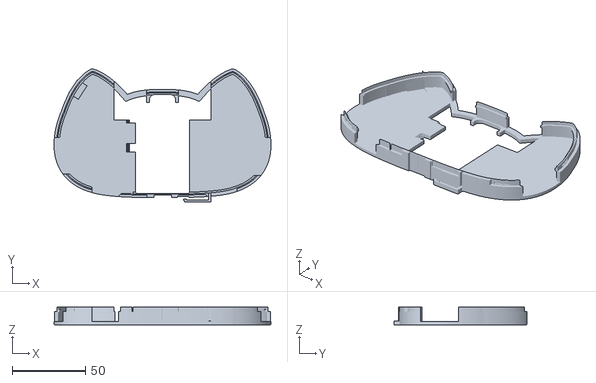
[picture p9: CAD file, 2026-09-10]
work/v8_7/preview/rear_tray_BLANK_ASSEMBLY.stl
148.0 x 90.8 x 12.2

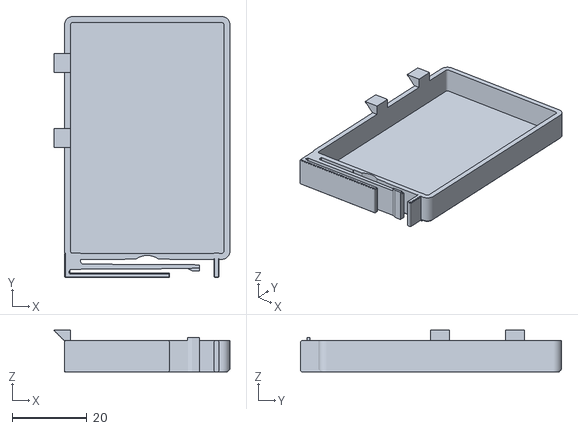
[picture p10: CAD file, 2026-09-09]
work/v8_7/reference/v84_battery_cover_ASSEMBLY.stl
47.0 x 69.8 x 11.1

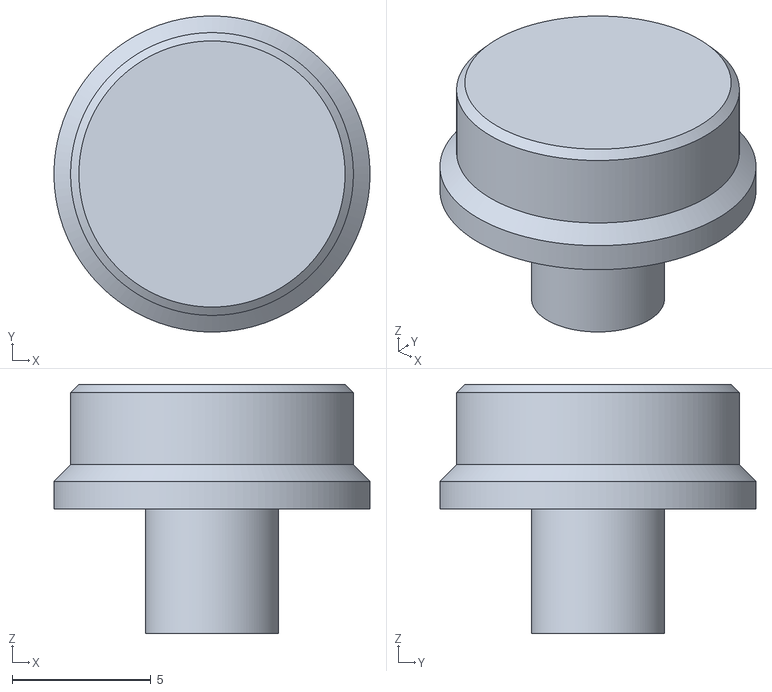
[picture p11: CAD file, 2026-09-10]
work/v8_7b/preview/cap_G10p2_S3p0_PLUS1mm_ASSEMBLY.stl
11.4 x 11.4 x 9.00

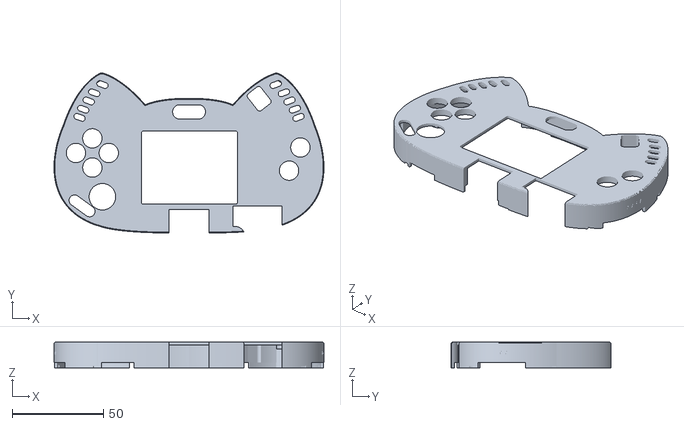
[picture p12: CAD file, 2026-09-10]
work/v8_7b/reference/faceplate_NO_SPRING_ONLY_ASSEMBLY.stl
148.0 x 87.7 x 14.0

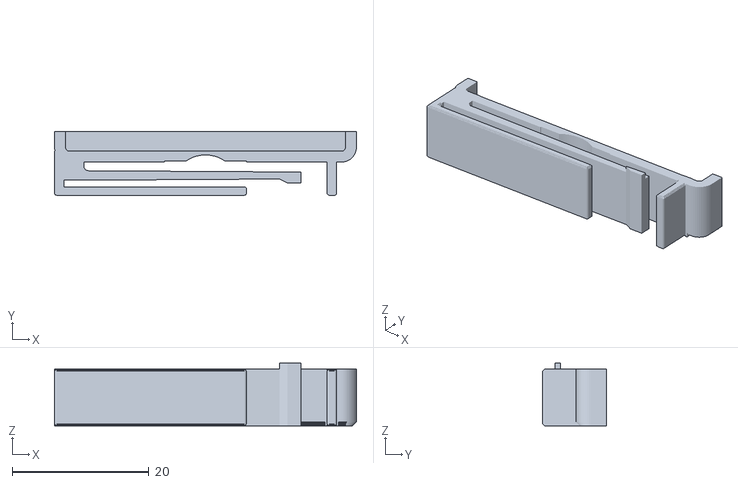
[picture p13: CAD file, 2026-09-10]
work/v8_7/preview/PRINT_FIRST_latch_cover_ASSEMBLY.stl
44.2 x 9.30 x 9.20

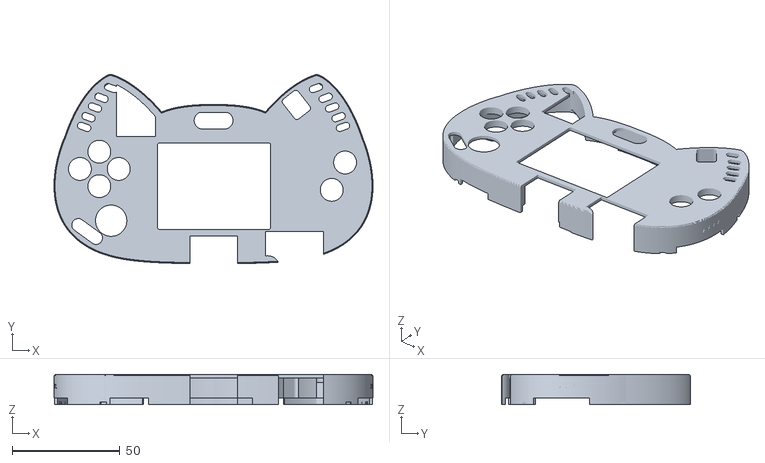
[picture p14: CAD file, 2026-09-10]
work/v8_7b/reference/faceplate_ASSEMBLY.stl
148.0 x 87.7 x 14.0

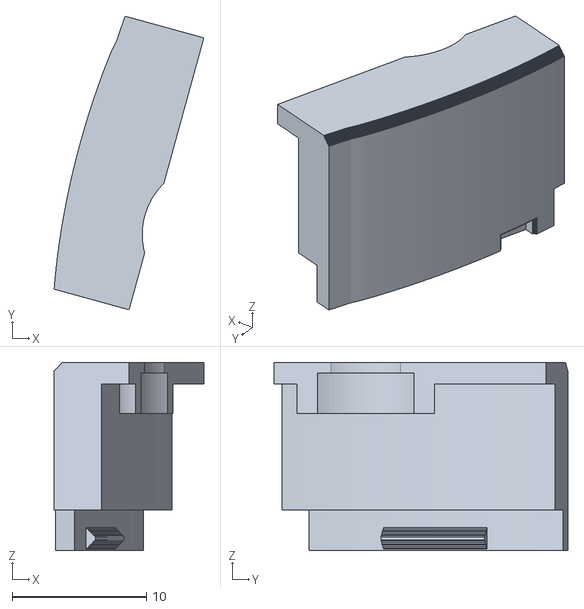
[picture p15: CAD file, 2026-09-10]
work/v8_7/preview/PRINT_FIRST_rim_lid_0p45_ASSEMBLY.stl
11.2 x 21.9 x 14.0

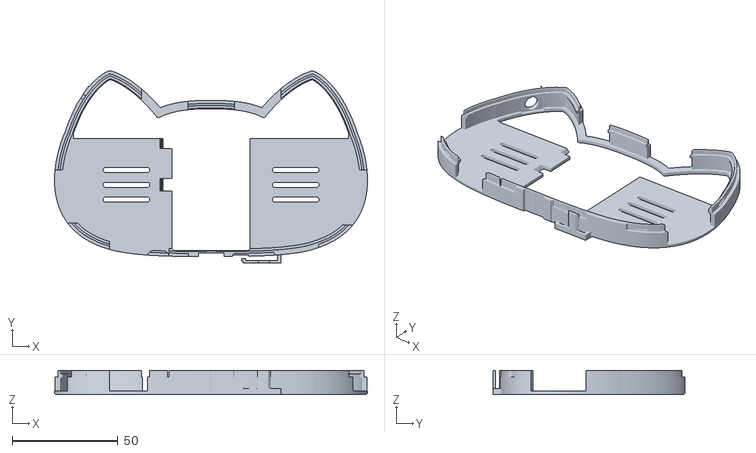
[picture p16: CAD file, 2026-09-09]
work/v8_7/reference/v84_rear_tray_ASSEMBLY.stl
148.0 x 90.8 x 11.4

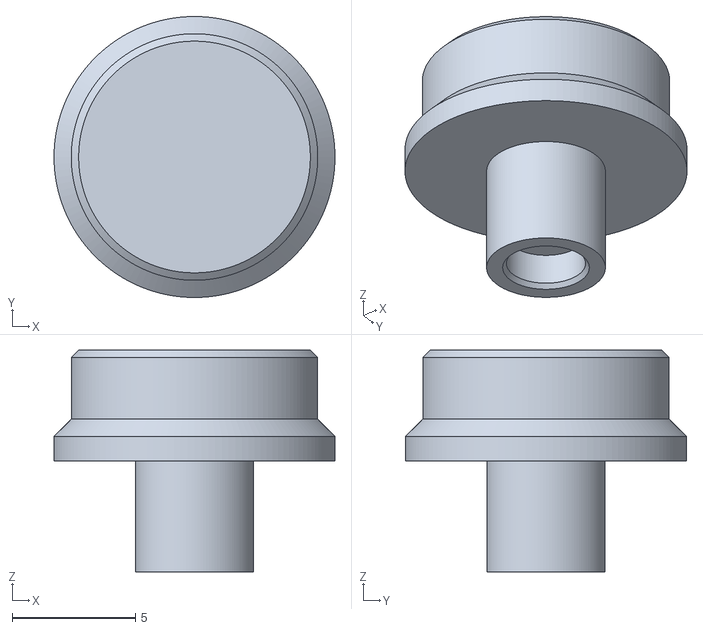
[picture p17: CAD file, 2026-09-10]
work/v8_7b/preview/cap_G10p0_S3p2_PLUS1mm_ASSEMBLY.stl
11.4 x 11.4 x 9.00

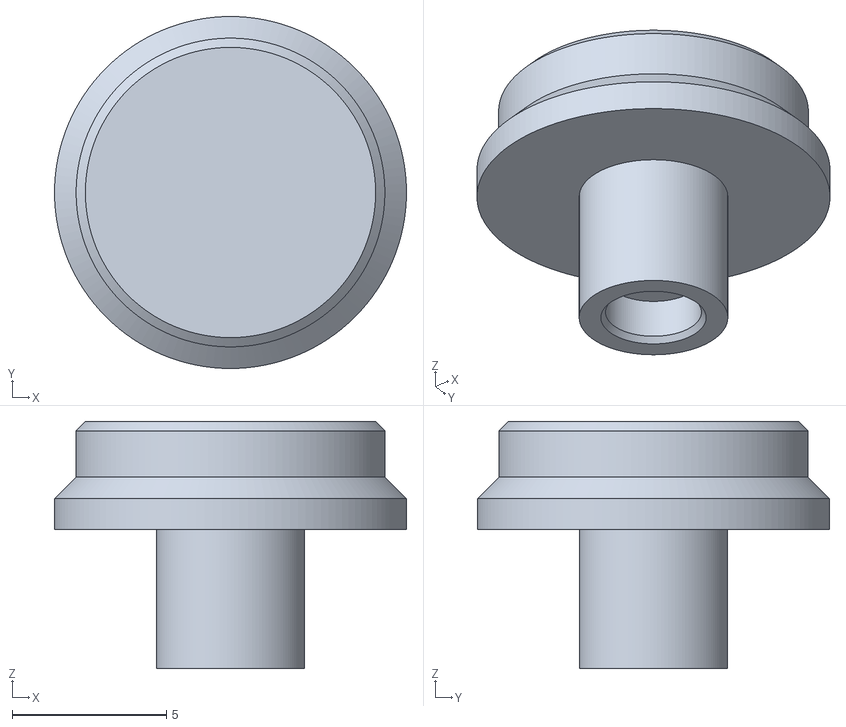
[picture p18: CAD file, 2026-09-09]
work/v8_7b/reference/cap_socket_3p1_ASSEMBLY.stl
11.4 x 11.4 x 8.00

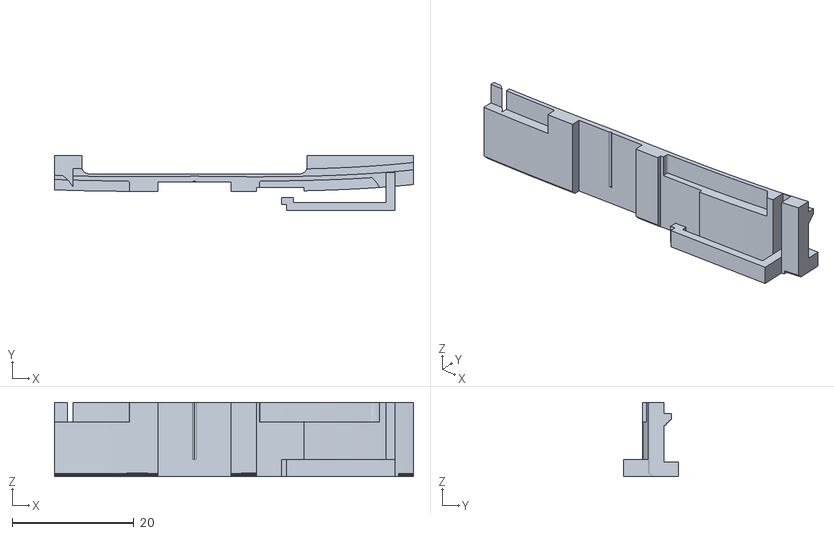
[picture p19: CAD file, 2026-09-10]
work/v8_7/preview/PRINT_FIRST_latch_tray_ASSEMBLY.stl
59.0 x 9.00 x 12.2

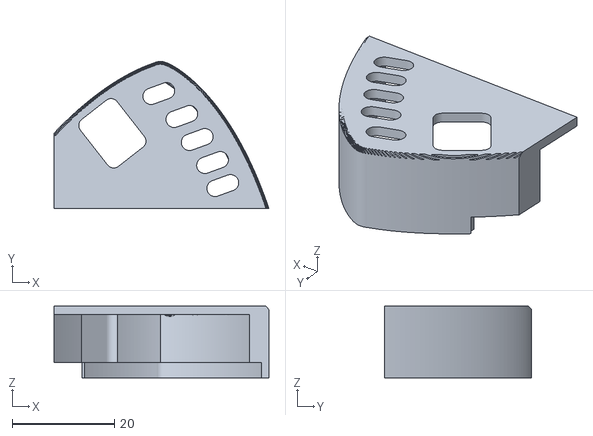
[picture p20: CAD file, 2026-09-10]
work/v8_7/preview/PRINT_FIRST_right_ear_SAO_ASSEMBLY.stl
42.0 x 28.8 x 14.0

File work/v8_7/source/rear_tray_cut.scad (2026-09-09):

difference(){
import("../preview/rear_tray_BLANK_ASSEMBLY.stl");
multmatrix([[-0.5478110923262648, 0, -0.8366020601960676, -58.657879930731475], [-0.8366020601960676, 0, 0.5478110923262648, 30.395197544675803], [0, 1, 0, -5.0], [0, 0, 0, 1]]) linear_extrude(height=20,center=true){union(){
polygon(points=[[-0.0,-3.25],[0.15947,-3.246085],[0.318556,-3.23435],[0.476874,-3.214824],[0.634044,-3.187552],[0.789686,-3.152602],[0.943425,-3.110056],[1.094892,-3.060018],[1.243721,-3.002608],[1.389554,-2.937965],[1.532039,-2.866244],[1.670834,-2.787618],[1.805603,-2.702276],[1.936023,-2.610424],[2.061778,-2.512284],[2.182567,-2.408091],[2.298097,-2.298097],[2.408091,-2.182567],[2.512284,-2.061778],[2.610424,-1.936023],[2.702276,-1.805603],[2.787618,-1.670834],[2.866244,-1.532039],[2.937965,-1.389554],[3.002608,-1.243721],[3.060018,-1.094892],[3.110056,-0.943425],[3.152602,-0.789686],[3.187552,-0.634044],[3.214824,-0.476874],[3.23435,-0.318556],[3.246085,-0.15947],[3.25,0.0],[3.246085,0.15947],[3.23435,0.318556],[3.214824,0.476874],[3.187552,0.634044],[3.152602,0.789686],[3.110056,0.943425],[3.060018,1.094892],[3.002608,1.243721],[2.937965,1.389554],[2.866244,1.532039],[2.787618,1.670834],[2.702276,1.805603],[2.610424,1.936023],[2.512284,2.061778],[2.408091,2.182567],[2.298097,2.298097],[0.0,4.596194],[-2.298097,2.298097],[-2.408091,2.182567],[-2.512284,2.061778],[-2.610424,1.936023],[-2.702276,1.805603],[-2.787618,1.670834],[-2.866244,1.532039],[-2.937965,1.389554],[-3.002608,1.243721],[-3.060018,1.094892],[-3.110056,0.943425],[-3.152602,0.789686],[-3.187552,0.634044],[-3.214824,0.476874],[-3.23435,0.318556],[-3.246085,0.15947],[-3.25,0.0],[-3.246085,-0.15947],[-3.23435,-0.318556],[-3.214824,-0.476874],[-3.187552,-0.634044],[-3.152602,-0.789686],[-3.110056,-0.943425],[-3.060018,-1.094892],[-3.002608,-1.243721],[-2.937965,-1.389554],[-2.866244,-1.532039],[-2.787618,-1.670834],[-2.702276,-1.805603],[-2.610424,-1.936023],[-2.512284,-2.061778],[-2.408091,-2.182567],[-2.298097,-2.298097],[-2.182567,-2.408091],[-2.061778,-2.512284],[-1.936023,-2.610424],[-1.805603,-2.702276],[-1.670834,-2.787618],[-1.532039,-2.866244],[-1.389554,-2.937965],[-1.243721,-3.002608],[-1.094892,-3.060018],[-0.943425,-3.110056],[-0.789686,-3.152602],[-0.634044,-3.187552],[-0.476874,-3.214824],[-0.318556,-3.23435],[-0.15947,-3.246085]],paths=[[0,1,2,3,4,5,6,7,8,9,10,11,12,13,14,15,16,17,18,19,20,21,22,23,24,25,26,27,28,29,30,31,32,33,34,35,36,37,38,39,40,41,42,43,44,45,46,47,48,49,50,51,52,53,54,55,56,57,58,59,60,61,62,63,64,65,66,67,68,69,70,71,72,73,74,75,76,77,78,79,80,81,82,83,84,85,86,87,88,89,90,91,92,93,94,95,96,97]],convexity=12);
}}
}

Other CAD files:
work/v8_7b/preview/cap_G10p3_S3p2_PLUS1mm_ASSEMBLY.stl
work/v8_7b/preview/cap_G10p2_S3p1_PLUS1mm_ASSEMBLY.stl
work/v8_7b/reference/cap_socket_3p0_ASSEMBLY.stl
work/v8_7b/preview/cap_G10p2_S3p2_PLUS1mm_ASSEMBLY.stl
work/v8_7b/reference/cap_socket_3p2_ASSEMBLY.stl
work/v8_4/CatBadge-v8.4-COMBINED-HANDHELD-NO-SPRING-ONLY.3mf
work/v8_4/CatBadge-v8.4-COMBINED-HANDHELD.3mf
work/v8_4/PRINT_FIRST_v8.4_Comfort_Only.3mf
work/v8_4/PRINT_FIRST_v8.4_Fit_and_Comfort.3mf
work/v8_4/parts/battery_cover.3mf
work/v8_4/parts/battery_cover.stl
work/v8_4/parts/cap_socket_3p0.3mf
work/v8_4/parts/cap_socket_3p1.3mf
work/v8_4/parts/cap_socket_3p2.3mf
work/v8_4/parts/cap_socket_3p3.3mf
work/v8_4/parts/faceplate.3mf
work/v8_4/parts/faceplate.stl
work/v8_4/parts/faceplate_NO_SPRING_ONLY.3mf
work/v8_4/parts/faceplate_NO_SPRING_ONLY.stl
work/v8_4/parts/rear_tray.3mf
work/v8_4/parts/rear_tray.stl
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

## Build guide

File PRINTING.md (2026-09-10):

# Printing trials

Starting trial for an **AnkerMake M5C with a 0.4 mm nozzle**, using eufyMake Studio 3D. Plate coating, filament formulation, calibration and environment matter. These settings have not been verified by a successful print of the latest parts. Geometry-only 3MF files do not apply settings automatically.

## Transparent HS PETG case trial

The reported spool label specifies 220–260°C nozzle and 60–80°C bed; exact brand/formulation is unconfirmed. Follow the instructions for your actual spool.

| Setting | Proposed trial |
| --- | --- |
| Layer height, including first layer | 0.20 mm |
| Wall loops / perimeters | 4 |
| Nozzle / bed temperature | 240°C / 80°C |
| First-layer speed / acceleration | 20 mm/s / 500 mm/s² |
| First-layer extrusion width | 0.50 mm |
| First-layer single-wall mode | Off |
| Outer / inner wall speed | 40 / 60 mm/s |
| Sparse infill speed | 80 mm/s |
| Fan | Off for 3 layers; 40% thereafter, separate bridge cooling |
| Rear brim | 8 mm outer brim, zero gap |
| Supports | Off, subject to sliced-path inspection |

Prepare your plate coating according to its manufacturer's instructions; keep direct room-fan/AC airflow away. PETG can adhere excessively to some surfaces, so no universal glue, solvent or Z-offset setting is prescribed here. Inspect first-layer contact and ensure the plate is seated properly.

V8.7a pads add two 0.20 mm layers of contact. Print the rear alone, center it, and verify pads and brim join the case. Let the plate and print cool, then support the ears while trimming. Do not twist the case to break off pads.

## Buttons and feedback

Print faces down, sockets up, at 100% scale. Clear brim remnants from the face bevel and socket mouth. Test the comparison caps in the actual faceplate before choosing a set; smaller clearance is not automatically a better fit.

Record exact file/version, filament, printer/nozzle/plate, layer height, temperatures, cooling, brim, and when lifting begins. For the case, record seam seating and retention. For buttons, record free sliding, socket grip and release without preload. A small coupon does not predict full-case warping.

Background: [Prusa warping guidance](https://help.prusa3d.com/article/warping_2011) and [PETG guidance](https://help.prusa3d.com/article/petg_2059). The specific settings above remain a trial, not a universally validated profile.

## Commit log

2026-09-09 feat: publish validated CatBadge v8.4 prototype
    [CatBadge-v8.4-COMBINED-HANDHELD-NO-SPRING-ONLY.3mf, CatBadge-v8.4-COMBINED-HANDHELD.3mf, PRINT_FIRST_cheek_grip.3mf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]
2026-09-10 feat: publish v8.7 case and adhesion and button upgrades
    [CatBadge-v8.7-COMBINED-CLOSED-BACK-NO-SPRING-ONLY.3mf, CatBadge-v8.7-COMBINED-CLOSED-BACK.3mf, CatBadge-v8.7a-Rear-Tray-Adhesion-Tabs.3mf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]
